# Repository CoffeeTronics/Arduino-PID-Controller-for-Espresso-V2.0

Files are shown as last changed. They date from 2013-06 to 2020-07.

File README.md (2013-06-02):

Arduino-PID-Controller-for-Espresso-V2.0
========================================

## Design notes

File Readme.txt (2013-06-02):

***How to use this software***

Download & install Arduino IDE v1.0 from http://arduino.cc/en/main/software
Copy the CONTENTS of the PID Libraries folder to your Arduino libraries folder.

***To use the Arduino Autotune backend and Processing backend
Download and install the latest version of Processing (I used V1.5.1)
Download and install the ControlP5 library https://code.google.com/p/controlp5/downloads/list
Make sure you get the version of ControlP5 that is compatible with your version of Processing!

Now open Arduino IDE and open the AutotuneMAX31855.ino file
Click on the Verify button (looks like a "tick")
After it compiles, click on the Upload button (looks like a "->"), in the lower left corner when "Compiling" changes to "Uploading", tap the Reset buttin on the controller.
If you get an "avrdude" error, it indicates the Reset button press timing was incorrect. The Reset button press must be done as soon as soon as "Compiling" changes to "Uploading".

Open Processing and open the PID_FrontEnd_v03.pde file
Search (CTRL F) the file for "//EDIT" (without the quotations), these are the parts that the end user can/should change.
Click the Run button (looks like a "Play" button)
This will open a new window displaying the temperature, output and toggle buttons. If the temperature and setpoint traces fail to appear, close the window and click the Runn button again.
The value below or inside the toggle buttons is what the button has been set to, the value to the RHS of the button is what the Arduino backend is set to. 
To change a toggle setting, click on it, enter a value (for P,I,D, etc), click the SEND_TO_ARDUINO button.

To Autotune the controller, put the controller into Manual Mode, then starting from a very low Output value (~50), slowly increase until the system has reached equilibrium with
the Setpoint. Toggle the TOGGLE_TUNING button to ON, check that TUNING_AM is set to MANUAL, then click SEND_TO_ARDUINO.
The Autotune uses the Set Response method to obtain values.
When the TOGGLE_TUNING state to the RHS of the TOGGLE_TUNING button changes from ON to OFF, tuning is complete. The values to the RHS of each P, I and D are the Autotuned
values.

***To use the PID Menu based Controller:
Open the Arduino IDE
Open the Arduino_PID_for_Espresso_V2_0.ino file
Enter the values obtained from the Autotune process into lines 120-122.
Click on the Verify button (looks like a "tick")
After it compiles, click on the Upload button (looks like a "->"), in the lower left corner when "Compiling" changes to "Uploading", tap the Reset buttin on the controller.
If you get an "avrdude" error, it indicates the Reset button press timing was incorrect. The Reset button press must be done as soon as soon as "Compiling" changes to "Uploading".

Once the code has uploaded, the display will read Arduino PID for Espresso, then change to the measured temp and "Menu".

To activate changes, button presses

Press ENTER to enter the Menu. The first item is Brew Espresso, press ENTER to set the Setpoint to the preselected Brew Temperature. The menu will return to root and the controller will move to the Brew Temperature Setpoint.

Press ENTER to enter the Menu. Move right to Steam Milk, press ENTER to set the Setpoint to the preselected Steaming Temperature. The menu will return to root.

Press ENTER to enter the Menu, move right to Brew Temp. the currect setting of Brew Temp will be displayed on the LCD. Press ENTER to enable changing of the Setpoint. The display will read Set Brew Point.
Use the L and R buttons to decrease and increase the Brewing Setpoint. When you have the Brew Setpoint you want, press ENTER to set it. The menu will return to root and the controller will move to the Setpoint. 
Now when you select Brew Espresso, the setpoint will move to the setpoint you have selected.

Press ENTER to enter the Menu, move right to Steam Temp, the currect setting of Steam Temp will be displayed on the LCD. Press ENTER to enable changing of the Steam Temp setting. The display will read Set Steam Point.
Use the L and R buttons to decrease and increase the Steaming Setpoint. When you have the Steaming Setpoint you want, press ENTER to set it. The menu will return to root and the controller will move to the Setpoint.
Now when you select Steam Milk, the setpoint will move to the setpoint you have selected.

Press ENTER to enter the Menu, move right to Offset. The current temp offset between the boiler and the grouphead will be displayed on the LCD. Press ENTER to enable changing of the Offset setting. the display will read Set Offset.
Us the L and R button to decrease and increase the Offset between the boiler and grouphead. When you have the offset you want, press ENTER. The menu will return to root and the controller will move to the Setpoint + Offset.

Currently in the Menu, there is a menu item named Scale, this is for a future update, where the user will be able to select whether to diplay temps in Celcius or Fahrenheit. 

If you are in the Menu and wish to exit without changing any settings, press the ESC button.

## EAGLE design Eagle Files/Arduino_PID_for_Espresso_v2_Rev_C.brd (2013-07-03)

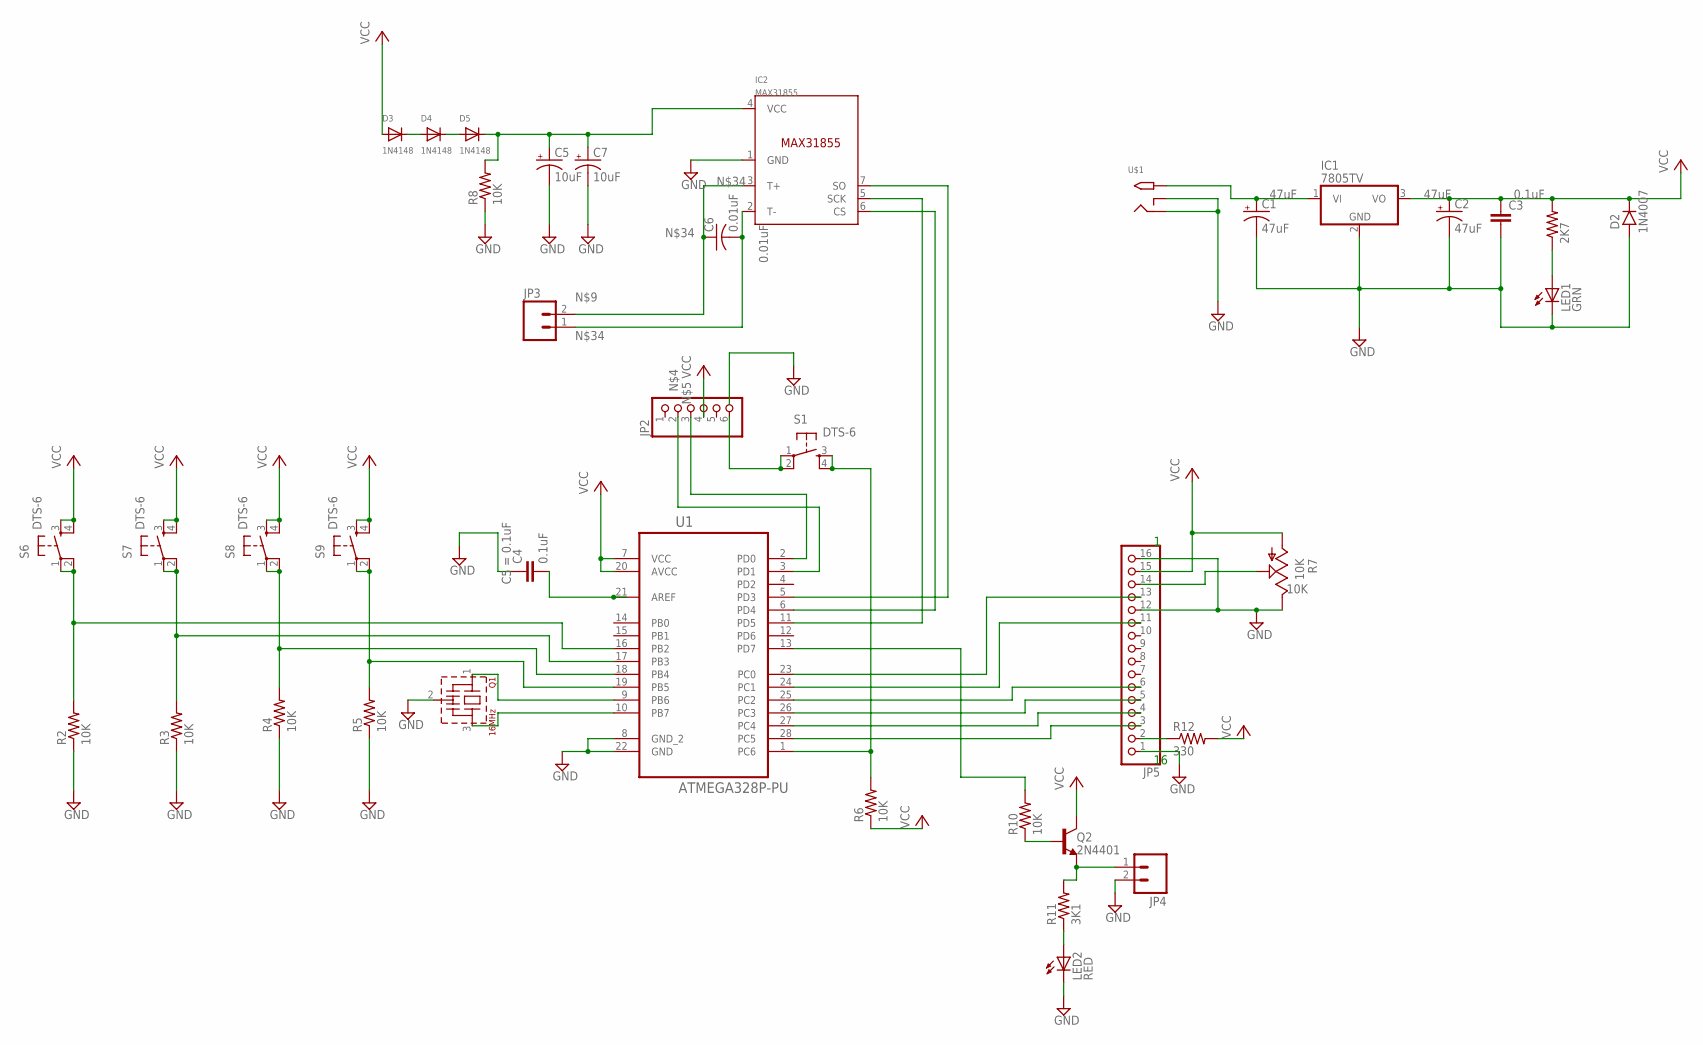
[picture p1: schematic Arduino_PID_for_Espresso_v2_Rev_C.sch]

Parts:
C1, C2: 47uF; TT5D6
C3: C-EU025-024X044; C025-024X044
C4: 0.1uF; C025-024X044
C5, C7: 10uF; CPOL-RADIAL-10UF-25V
C6: 0.01uF; C025-024X044
D2: 1N4007; DO41-3
D3, D4, D5: 1N4148; DO-1N4148
IC1: 7805TV; TO220V
IC2: MAX31855; SOIC8
JP2: PINHD-1X6/90; 1X06/90
JP3, JP4: M023.5MM; SCREWTERMINAL-3.5MM-2
JP5: PINHD-1X16; 1X16
LED1: GRN; LED3MM
LED2: RED; LED3MM
Q1: 16MHz; CSTLA_T
Q2: 2N4401; TO92-
R1: 2K7; AXIAL-0.4
R2, R3, R4, R5, R6, R8, R10: 10K; 1/6W-RES
R7: 10K; B25P
R11: 3K1; AXIAL-0.4
R12: 330; AXIAL-0.4
S1, S6, S7, S8, S9: DTS-6
U1: ATMEGA328P-PU; DIP254P762X457-28
U$1: 2.1MMJACKTHM; PJ-102A

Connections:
GND: C1.-, C2.-, C3.2, C4.1, C5.2 (-), C7.2 (-), D2.A, IC1.2 (GND), IC2.1 (GND), JP2.6, JP4.2, JP5.1, JP5.12, JP5.16, LED1.K (C), LED2.K (C), Q1.2 (VSS), R2.1, R3.1, R4.1, R5.1, R7.E, R8.1, S1.1, S1.2, U1.8 (GND_2), U1.22 (GND), U$1.RING, U$1.RING_SW
unnamed: C1.+, IC1.1 (VI), U$1.TIP
unnamed: C4.2, U1.21 (AREF)
unnamed: LED1.A, R1.P$1 (1)
unnamed: JP2.2, U1.3 (PD1)
unnamed: JP2.3, U1.2 (PD0)
unnamed: R2.2, S6.1, S6.2, U1.16 (PB2)
unnamed: JP5.14, R7.S
unnamed: JP5.2, R12.P$1 (1)
unnamed: C6.2, IC2.2 (T-), JP3.1
unnamed: R4.2, S8.1, S8.2, U1.18 (PB4)
unnamed: Q1.1, U1.9 (PB6)
unnamed: Q1.3, U1.10 (PB7)
unnamed: R6.2, S1.3, S1.4, U1.1 (PC6)
unnamed: R3.2, S7.1, S7.2, U1.17 (PB3)
unnamed: R5.2, S9.1, S9.2, U1.19 (PB5)
unnamed: JP5.3, U1.28 (PC5)
unnamed: JP5.4, U1.27 (PC4)
unnamed: IC2.6 (CS), U1.6 (PD4)
unnamed: JP5.5, U1.26 (PC3)
unnamed: IC2.7 (SO), U1.5 (PD3)
unnamed: IC2.5 (SCK), U1.11 (PD5)
unnamed: D3.C, D4.A
unnamed: D4.C, D5.A
unnamed: C5.1 (+), C7.1 (+), D5.C, IC2.4 (VCC), R8.2
unnamed: JP5.6, U1.25 (PC2)
unnamed: JP5.11, U1.24 (PC1)
unnamed: JP5.13, U1.23 (PC0)
unnamed: Q2.2 (B), R10.1
unnamed: JP4.1, Q2.3 (E), R11.P$2 (2)
unnamed: R10.2, U1.13 (PD7)
unnamed: LED2.A, R11.P$1 (1)
unnamed: C6.1, IC2.3 (T+), JP3.2
VCC: C2.+, C3.1, D2.C, D3.A, IC1.3 (VO), JP2.4, JP5.15, Q2.1 (C), R1.P$2 (2), R6.1, R7.A, R12.P$2 (2), S6.3, S6.4, S7.3, S7.4, S8.3, S8.4, S9.3, S9.4, U1.7 (VCC), U1.20 (AVCC)

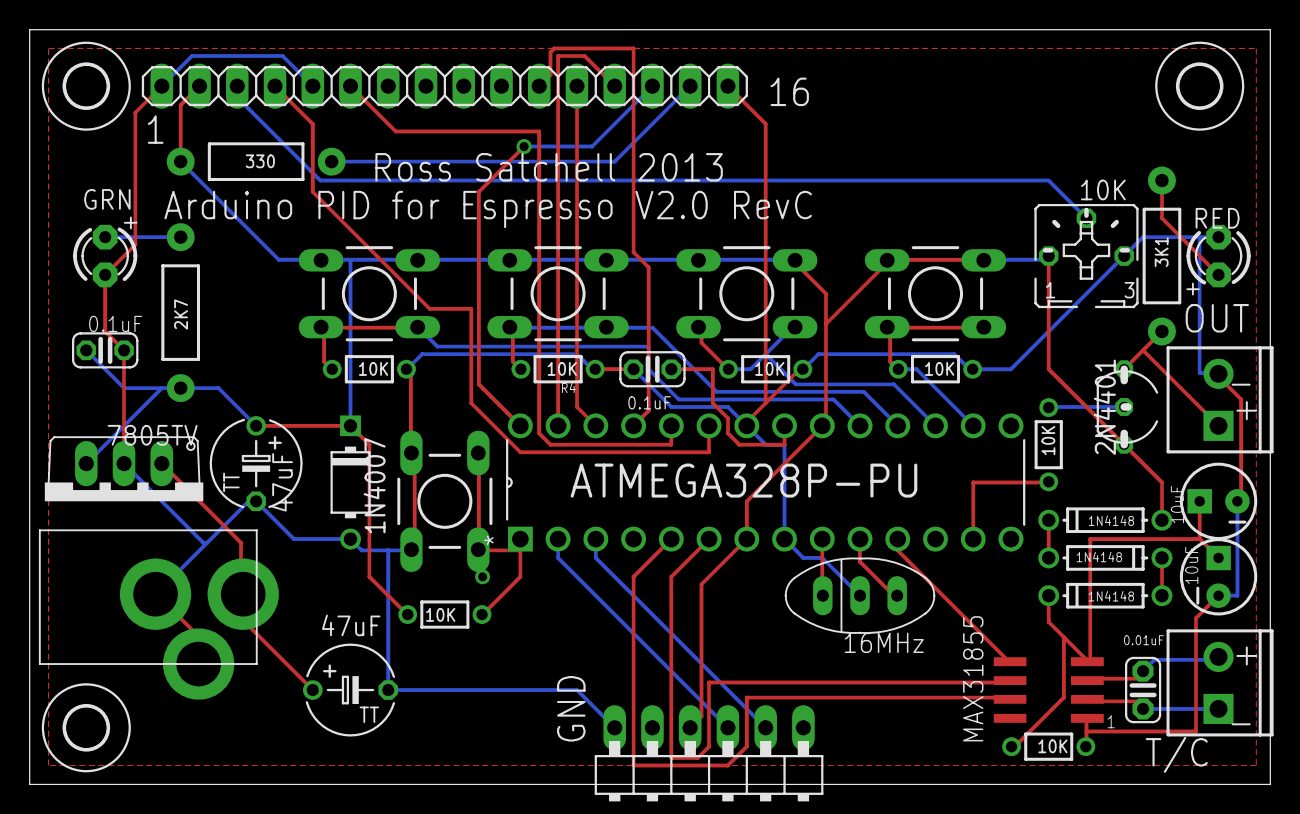
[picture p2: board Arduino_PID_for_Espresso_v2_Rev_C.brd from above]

Board: 2 copper layers, 83.5 x 50.8 mm, 42 parts (0 on the bottom side), 34 nets.

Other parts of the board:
U$2, U$3, U$4: 2,8

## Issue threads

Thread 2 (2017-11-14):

Error on compiling.  2 variables not declared.  Arduino 1.8.3

ML-Weiss, 2017-11-14:
Arduino_PID_for_Espresso_v2_0:87: error: 'menuUsed' was not declared in this scope

 MenuBackend menu = MenuBackend(menuUsed,menuChanged);

                                ^

Arduino_PID_for_Espresso_v2_0:87: error: 'menuChanged' was not declared in this scope

 MenuBackend menu = MenuBackend(menuUsed,menuChanged);

ML-Weiss, 2017-11-15:
Figured out the problem:

Add the following before MenuBackend(menuUseEvent,menuChangeEvent);

static void menuChangeEvent(MenuChangeEvent changed);
static void menuUseEvent(MenuUseEvent used);

Norrox, 2017-11-23:
@ML-Weiss
I changed what you said above but now we are getting these errors :S

C:\Users\UK\AppData\Local\Temp\cc1UkDbY.ltrans2.ltrans.o: In function `__base_ctor ':

C:\Program Files (x86)\Arduino\libraries\MenuBackend/MenuBackend.h:151: undefined reference to `menuChangeEvent(MenuChangeEvent)'

C:\Program Files (x86)\Arduino\libraries\MenuBackend/MenuBackend.h:151: undefined reference to `menuChangeEvent(MenuChangeEvent)'

C:\Program Files (x86)\Arduino\libraries\MenuBackend/MenuBackend.h:152: undefined reference to `menuUseEvent(MenuUseEvent)'

C:\Program Files (x86)\Arduino\libraries\MenuBackend/MenuBackend.h:152: undefined reference to `menuUseEvent(MenuUseEvent)'

collect2.exe: error: ld returned 1 exit status

exit status 1
Error compiling for board Arduino/Genuino Uno.

CoffeeTronics, 2017-11-24:
I found that using function prototypes fixed that problem.

On Nov 23, 2017 2:51 PM, "Christoffer Karlsson" <notifications@github.com>
wrote:

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

Arduino-n00b, 2019-08-06:
Hello folks.

I ran into this project and I think it is great.

I am having one issue after looking over the code and made the following corrections.

Add the following before MenuBackend(menuUseEvent,menuChangeEvent);

static void menuChangeEvent(MenuChangeEvent changed);
static void menuUseEvent(MenuUseEvent used);

After that it seemed to work aside from this error code:

Error compiling for board Arduino/Genuino Uno.

What am I doing wrong?

P.S. I want to use an SPI interface for the LCD but only after I can get it to compile with my IDE for my Uno.

I will share my alterations to this project and thank you in advance.

hikerlt1951, 2020-07-10:
Trying to compile this version V2.0, and get errors ( attached below). I am using the Jameco PID Temperature Controller kit part # 2190178, running arduino IDE 1.8.13 on windows 10 PC.

QUESTION - does anyone have a newer version that works, from the "Arduino PID for Espresso V2.0 by Ross Satchell 2013" ??

**Errors found when compiling V2.0:**

Arduino: 1.8.13 (Windows 10), Board: "Arduino Uno"

sketch_jul10b:87:32: error: 'menuUsed' was not declared in this scope

 MenuBackend menu = MenuBackend(menuUsed,menuChanged);

                                ^~~~~~~~

C:\Users\LT\AppData\Local\Temp\arduino_modified_sketch_182912\sketch_jul10b.ino:87:32: note: suggested alternative: 'menu'

 MenuBackend menu = MenuBackend(menuUsed,menuChanged);

                                ^~~~~~~~

                                menu

sketch_jul10b:87:41: error: 'menuChanged' was not declared in this scope

 MenuBackend menu = MenuBackend(menuUsed,menuChanged);

                                         ^~~~~~~~~~~

C:\Users\LT\AppData\Local\Temp\arduino_modified_sketch_182912\sketch_jul10b.ino: In function 'void setup()':

sketch_jul10b:679:6: error: redefinition of 'void setup()'

 void setup() {

      ^~~~~

C:\Users\LT\AppData\Local\Temp\arduino_modified_sketch_182912\sketch_jul10b.ino:132:6: note: 'void setup()' previously defined here

 void setup() {

      ^~~~~

C:\Users\LT\AppData\Local\Temp\arduino_modified_sketch_182912\sketch_jul10b.ino: In function 'void loop()':

sketch_jul10b:684:6: error: redefinition of 'void loop()'

 void loop() {

      ^~~~

C:\Users\LT\AppData\Local\Temp\arduino_modified_sketch_182912\sketch_jul10b.ino:171:6: note: 'void loop()' previously defined here

 void loop() {

      ^~~~

Multiple libraries were found for "Wire.h"

 Used: C:\Program Files (x86)\Arduino\hardware\arduino\avr\libraries\Wire

 Not used: C:\Program Files (x86)\Arduino\libraries\Wire

exit status 1

'menuUsed' was not declared in this scope

This report would have more information with
"Show verbose output during compilation"
option enabled in File -> Preferences.

hikerlt1951, 2020-07-11:
Thank You !

The fix in the program that you did works great !

Closed 2020-07-19.

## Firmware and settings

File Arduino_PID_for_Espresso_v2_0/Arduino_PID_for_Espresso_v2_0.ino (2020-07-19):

/*
********************************************************
  Arduino PID for Espresso V2.0 by Ross Satchell 2013  *
********************************************************
  This code is intended for single boiler espresso machines such as the Rancilio Silvia (I have been using one as a test machine)
  However it can be easily adapted for double boiler machines by setting up separate PID calls for each boiler. Of course seperate thermocouples and MAX31855's would be required
  It can be adapted for pretty much any application where a PID controller and a menu system is needed
  
 The code for this has been borrowed from several sources and modified to suit this purpose.
 It is a work in progress and will continue to be updated as time permits around my studies.
 
 I would like to thank Brett Beauregard http://brettbeauregard.com/blog for writing the PID library and answering my questions, 
 Konstantine Polanski for combining Brett's Autotune front end and backend for easy acquisition of initial tuning parameters   https://groups.google.com/forum/?fromgroups#!topic/diy-pid-control/4bm_SQrPe8c
 Adafruit for writing the MAX31855 library https://github.com/adafruit/Adafruit-MAX31855-library
 Alexander Brevig http://alexanderbrevig.github.io/ for writing the original menubackend library, 
 Giuseppe Di Cillo http://www.coagula.org/ for modifying the menubackend library to return to root,
 the Arduino community for providing the LCD library http://arduino.cc/en/Reference/LiquidCrystal?from=Tutorial.LCDLibrary  and for helping me solve problems,
 and my friend Daniel Croft for lending me his Rancilio Silvia, helping me along the way and committing code to Github for me!
 
 For those not very familiar with PID, I highly recommend Brett's Beginners posts http://brettbeauregard.com/blog/2011/04/improving-the-beginners-pid-introduction/
  
 This code has been tested in Arduino IDE V1.0 
 For modification and debugging, uncomment the Serial.print lines to print to the Serial Window to make changes easier to detect
 
 The LCD (HD44780 compatible) is connected in 4-bit mode with connections as follows:-
 * LCD Enable pin to digital pin 11
 * LCD D4 pin to digital pin 5
 * LCD D5 pin to digital pin 4
 * LCD D6 pin to digital pin 3
 * LCD D7 pin to digital pin 2
 * LCD R/W pin to ground
 * 10K resistor:
 * ends to +5V and ground
 * wiper to LCD VO pin (pin 3)
 
 To get initial tuning parameter via the Autotune function, join the diy-pid-control google group and see Konstantine's post (linked above, dated Feb 28 2013) for instructions on how to use the Autotune
 frontend and backend.  I plan to integrate my code into the Autotune backend as time allows to simplify things. Currently, I use the autotune to get my parameters, then load them into this code at Lines 118-120.
 */


#include <LiquidCrystal.h>
#include <Adafruit_MAX31855.h>
#include <MenuBackend.h>
#include <Wire.h>
#include <PID_v1.h>
#define RelayPin 7    // SSR connected to Arduino digital 7

int thermoDO = 3;    // MAX31855 Data to Arduino digital 3
int thermoCS = 4;    // MAX31855 Chip Select to Arduino digital 4
int thermoCLK = 5;    // MAX31855 Clock to Arduino digital 5

int right;    // boolean for right button
int left;      // boolean for left button
int enter;    // boolean for enter button
int escape;    // boolean for esc button
int setBrewTemp; //boolean variabke for storing whether user is in Brew Set Point part of menu 
int setSteamTemp;  //boolean variabke for storing whether user is in Steam Set Point part of menu 
int setOffsetBool; // boolean for storing whether user is in Set Offset part of menu
int setTempScale; // boolean for storing whether user is in Set TempScale part of menu
int setBrewing;  // boolean for storing whether user is in Brew Espresso part of menu
int setSteaming;  // boolena for storing whewther user is in Steam Milk part of menu

double brewTempSetting = 200.00; //variable for allowing setting of brew setpoint when in Set Brew Temp part of menu
double steamTempSetting = 250.00; //variable for allowing setting of steam setpoint when in Set Brew Temp part of menu
int intBrewTempSetting;  // int for displaying brewTempSetting in integer for to save lcd space (MAY NOT BE USED)
int intSteamTempSetting;  // int for displaying steamTempSetting in integer for to save lcd space (MAY NOT BE USED)
double offsetSetting;  // value for changing/displaying temp offset from boiler to grouphead 

const int buttonPinLeft = 13; // pin for the Up button
const int buttonPinRight = 10; // pin for the Down button
const int buttonPinEsc = 12; // pin for the Esc button
const int buttonPinEnter = 11; // pin for the Enter button

int lastButtonPushed = 0;    // initialise 
int lastButtonEnterState = LOW; // the previous reading from the Enter input pin
int lastButtonEscState = LOW; // the previous reading from the Esc input pin
int lastButtonLeftState = LOW; // the previous reading from the Left input pin
int lastButtonRightState = LOW; // the previous reading from the Right input pin

long lastEnterDebounceTime = 0; // the last time the output pin was toggled
long lastEscDebounceTime = 0; // the last time the output pin was toggled
long lastLeftDebounceTime = 0; // the last time the output pin was toggled
long lastRightDebounceTime = 0; // the last time the output pin was toggled
long debounceDelay = 300; // the debounce time

//it's necessary to manually add the prototypes for the menuUsed and menuChanged functions here because the Arduino IDE's
//automated function prototype generation system inserts them after they are referenced in the MenuBackend instantiation
void menuUsed(MenuUseEvent used);
void menuChanged(MenuChangeEvent changed);

//Menu variables
MenuBackend menu = MenuBackend(menuUsed,menuChanged);
//initialize menu items
MenuItem menu1Item1 = MenuItem("Brew Espresso");  // select this to load preset brewing setpoint
MenuItem menu1Item2 = MenuItem("Steam Milk");    // select this to load preset steam stepoint
MenuItem menu1Item3 = MenuItem("Brew Temp");    // select this and move to child to change brew setpoint
MenuItem menuItem3SubItem1 = MenuItem("Set Brew Point");  // select this to change brew setpoint
MenuItem menu1Item4 = MenuItem("Steam Temp");            // select this and move to child to change steam setpoint
MenuItem menuItem4SubItem1 = MenuItem("Set Steam Point");  // select this to change steam setpoint
MenuItem menu1Item5 = MenuItem("Offset");                  // select this & move to child to change boiler to group temp offset
MenuItem menuItem5SubItem1 = MenuItem("Set Offset");        // select this to change boiler to group temp offset
MenuItem menu1Item6 = MenuItem("Scale");                    // select this & move to child to change temp scale
MenuItem menuItem6SubItem1 = MenuItem("Set Scale");         // select this to change temp scale

long unsigned lastMillis;
unsigned long nowMillis;
double minutes;

Adafruit_MAX31855 thermocouple(thermoCLK, thermoCS, thermoDO);    // initialise MAX31855 chip

const int numReadings = 10;      // number of readings in array. Increase if slower more stable readings are reqd, reduce if faster readings are reqd

double readings[numReadings];      // the readings from thermocouple
int index = 0;                  // the index of the current reading
double total = 0.0;                  // the running total
double averageF = 0.0;                // the average      
double tempReadF = 0.0;              // temp read in F
double tempReadC = 0.0;              // temp read in C

LiquidCrystal lcd(14, 15, 16, 17, 18, 19);  // initialize the library with the numbers of the interface pins


double Setpoint, Input, Output;    //Define PID variables we'll be connecting to

float Kp = 16.16;    //User inserts PID values obtaines from Autotune here
float Ki = 0.14;    //
float Kd = 480.10;  //

PID myPID(&Input, &Output, &Setpoint,Kp, Ki, Kd, DIRECT);  //Specify the links and initial tuning parameters


int WindowSize = 1000;    // I have found for espresso machines that a 1000ms window does well
unsigned long windowStartTime;  // used in calculating PID output pulse length
double timeNowMins;                // used for logging time in Serial Window


void setup() {
   
  Serial.begin(9600);
  pinMode(buttonPinLeft, INPUT);    //setup input buttons
  pinMode(buttonPinRight, INPUT);
  pinMode(buttonPinEnter, INPUT);
  pinMode(buttonPinEsc, INPUT);
  
  for (int thisReading = 0; thisReading < numReadings; thisReading++)      // initialize all the readings to 0: 
    readings[thisReading] = 0;    


  lcd.begin(16, 2);        // set up the LCD's number of rows and columns: 
  lcd.clear();              // clear LCD
  lcd.setCursor(0,0);        // set cursor to column 1, row 1
  lcd.print("Arduino PID");    //SPLASH
  lcd.setCursor(4,1);          //SCREEN
  lcd.print("for Espresso");
  delay(3000);          // delay for dramatic effect!
  lcd.clear();          // clear lcd
  
  windowStartTime = millis();    // set window to current millis value
  Setpoint = 200;  //Default Setpoint for Rancilio Silvia for approx 200F at the group head
  offsetSetting = 12.00;
  myPID.SetOutputLimits(0, WindowSize);   //tell the PID to range between 0 and the full window size
  myPID.SetMode(AUTOMATIC);    //turn the PID on
  
  //configure menu structure
menu.getRoot().add(menu1Item1);
menu1Item1.addRight(menu1Item2).addRight(menu1Item3).addRight(menu1Item4).addRight(menu1Item5).addRight(menu1Item6);
menu1Item3.add(menuItem3SubItem1);
menu1Item4.add(menuItem4SubItem1);
menu1Item5.add(menuItem5SubItem1); 
menu1Item6.add(menuItem6SubItem1);

menu.toRoot();    // go to root of menu
  
}

void loop() {
  tempRead();    // call temp reading method
  
  if ((millis() - lastMillis) >= 125)  {    //perform calcPID 8 times per second
  calcPID();    // call PID calculation
  readButtons(); //  button reading and navigation split in two procedures because 
  navigateMenus(); //in some situations, the buttons are used for other purpose (eg. to change some settings)
  changeValues(); // scans buttons and menu states
  }
 
}  // end loop

void tempRead()  {
   double c = thermocouple.readCelsius();
   if (isnan(c)) {    //  if c is not a number
     //Serial.println("Something wrong with thermocouple!"); // uncomment if using serial window
     lcd.setCursor(0,0);
     lcd.print("Thermocouple Err");
   } else {
    // Serial.print("C = "); 
    // Serial.println(c);
   }

   tempReadF = thermocouple.readFarenheit();  // read temp in degrees F
   tempReadC = c;                            // temp in degrees C
    
   total= total - readings[index];         
   readings[index] = tempReadF;         // read from the sensor: 
   total= total + readings[index];     // add the reading to the total:    
   index = index + 1;                 // advance to the next position in the array:         
   if (index >= numReadings)          // if we're at the end of the array...
   index = 0;                         // ...wrap around to the beginning:                          
   averageF = total / numReadings;    // calculate the average:
    
   //Serial.print("Internal Temp = ");        // uncomment these lines if checking MAX31855 
   //Serial.println(thermocouple.readInternal());     // internal chip temp via Serial Window
   //Serial.print("Temp ");                    // uncomment these lines if checking MAX31855
   Serial.print(averageF);                  // hot junction temp via Serial Window
   Serial.print("\t");
   lcd.setCursor(9,0);
   lcd.print(averageF);      // print temp to upper RHS of LCD
   lcd.print((char)223);          // print degree symbol
   
   
}
   
void calcPID()  {
  Input = averageF; // PID input is measured averaged temp
  myPID.Compute(); //PID calculation
  
  /************************************************
  * turn the output pin on/off based on pid output
  ************************************************/
  unsigned long now = millis();
  if(now - windowStartTime>WindowSize)    //time to shift the Relay Window
    { 
    windowStartTime += WindowSize;
    }
  if(Output > now - windowStartTime) digitalWrite(RelayPin,HIGH);
  else digitalWrite(RelayPin,LOW);
  
  Serial.print(Output);    // uncomment these lines if
  Serial.print("\t");      // logging data to  
  timeNowMins = millis() / 60000.0;    //Serial 
  Serial.println(timeNowMins);        // Window
}

void menuChanged(MenuChangeEvent changed){

MenuItem newMenuItem=changed.to; //get the destination menu

lcd.setCursor(0,1); //set the start position for lcd printing to the second row, first column

if(newMenuItem.getName()==menu.getRoot()){
  lcd.setCursor(0,0);
  lcd.print("       ");
  lcd.setCursor(0,1);
  lcd.print("Menu            ");
  setBrewTemp = false; 
  setSteamTemp = false;
  setOffsetBool = false;
  setTempScale = false;

}else if(newMenuItem.getName()=="Brew Espresso"){
    lcd.setCursor(0,0);
    lcd.print("       ");
    lcd.setCursor(0,1);
    lcd.print("Brew Espresso   ");
    setBrewTemp = false;
    setSteamTemp = false;
    setBrewing = true;
    setSteaming = false;
    setOffsetBool = false;
    setTempScale = false;

}else if(newMenuItem.getName()=="Steam Milk")  {
    lcd.setCursor(0,0);
    lcd.print("       ");
    lcd.setCursor(0,1);
    lcd.print("Steam Milk      ");
    setBrewTemp = false;
    setSteamTemp = false;
    setOffsetBool = false;
    setTempScale = false;
    setSteaming = true;
    setBrewing = false;

}else if(newMenuItem.getName()=="Brew Temp"){
    lcd.setCursor(0,0);
    lcd.print("       ");
    lcd.setCursor(0,0);
    lcd.print(brewTempSetting);
    lcd.setCursor(0,1);
    lcd.print("Brew Temp       "); 
    setBrewTemp = false;
    setSteamTemp = false;
    setOffsetBool = false;
     setTempScale = false;


}else if (newMenuItem.getName()=="Set Brew Point"){
    lcd.setCursor(0,0);
    lcd.print("       ");
    lcd.setCursor(0,1);  
    lcd.print("Set Brew Point  ");
    lcd.setCursor(0,0);
    lcd.print(brewTempSetting);
    setBrewTemp = true;
    setSteamTemp = false;
    setOffsetBool = false;
    setTempScale = false;
    
}else if (newMenuItem.getName()=="Steam Temp")  {
    lcd.setCursor(0,0);
    lcd.print("       ");
    lcd.setCursor(0,1);
    lcd.print("Steam Temp      ");
    lcd.setCursor(0,0);
    lcd.print(steamTempSetting);
    setBrewTemp = false;
    setSteamTemp = false;
    setOffsetBool = false;
    setTempScale = false;
  
}else if (newMenuItem.getName()=="Set Steam Point")  {
    lcd.setCursor(0,0);
    lcd.print("       ");
    lcd.setCursor(0,0);
    lcd.print(steamTempSetting);
    lcd.setCursor(0,1);
    lcd.print("Set Steam Point ");
    setBrewTemp = false;
    setSteamTemp = true;
    setOffsetBool = false;
    setTempScale = false;


}else if(newMenuItem.getName()=="Offset")  {
    lcd.setCursor(0,0);
    lcd.print("       ");
    lcd.setCursor(0,0);
    lcd.print(offsetSetting);
    lcd.setCursor(0,1);
    lcd.print("Offset          ");
    setBrewTemp =false;
    setSteamTemp = false;
    setOffsetBool = false;
    setTempScale = false;
  
}else if(newMenuItem.getName()=="Set Offset")  {
    lcd.setCursor(0,0);
    lcd.print("       ");
    lcd.setCursor(0,1);
    lcd.print("Set Offset");
    lcd.setCursor(0,0);
    lcd.print(offsetSetting);
    setBrewTemp =false;
    setSteamTemp = false;
    setOffsetBool = true;
    setTempScale = false;
    
}else if(newMenuItem.getName()=="Scale")  {   
    lcd.setCursor(0,0);
    lcd.print("       ");
    lcd.setCursor(0,1);
    lcd.print("Scale  "); 
    setBrewTemp =false;
    setSteamTemp = false;
    setOffsetBool = false;
    setTempScale = false;
    
}else if(newMenuItem.getName()=="Set Scale")  {   
    lcd.setCursor(0,0);
    lcd.print("       ");
    lcd.setCursor(0,1);
    lcd.print("Set Scale");
    setBrewTemp =false;
    setSteamTemp = false;
    setOffsetBool = false;
    setTempScale = true;
    
}else  {
    setBrewTemp =false;
    setSteamTemp = false;
    setTempScale = false;
    }
  }
  
void menuUsed(MenuUseEvent used) {
  
  if ((setBrewTemp == true) && (enter == true))  {
     //Serial.print("brew temp selected = ");  // uncomment for Serial 
     //Serial.println(brewTempSetting);        // Window debugging
     Setpoint = brewTempSetting + offsetSetting;
     menu.toRoot();
     
  }else if ((setSteamTemp == true) && (enter == true))  {
     //Serial.print("Steam temp Selected = ");
     //Serial.println(steamTempSetting);
     Setpoint = steamTempSetting;
     menu.toRoot();
     
    
  }else if ((setOffsetBool == true) && (enter == true))  {
    //Serial.print("Offset now set to ");
    //Serial.println(offsetSetting);
    Setpoint = brewTempSetting + offsetSetting;
    menu.toRoot();
    
  
  }else if ((setBrewing == true) && (enter == true))  {
    Setpoint = brewTempSetting + offsetSetting;
    lcd.setCursor(0,0);
    lcd.print("       ");
    lcd.setCursor(0,0);
    lcd.print(Setpoint);
    //Serial.print("ESPRESSO ");
    //Serial.println(Setpoint);
    menu.toRoot();
    
  }else if ((setSteaming == true) && (enter == true))  {
    Setpoint = steamTempSetting;
    lcd.setCursor(0,0);
    lcd.print("       ");
    lcd.setCursor(0,0);
    lcd.print(Setpoint);
    //Serial.print("STEAMING ");
    //Serial.println(Setpoint);
    menu.toRoot();
    
  
  
  }else{
    
     menu.toRoot();
     Setpoint = brewTempSetting + offsetSetting;
  }
}

void readButtons(){ //read buttons status
int reading;
int buttonEnterState=LOW; // the current reading from the Enter input pin
int buttonEscState=LOW; // the current reading from the input pin
int buttonLeftState=LOW; // the current reading from the input pin
int buttonRightState=LOW; // the current reading from the input pin

//Enter button
// read the state of the switch into a local variable:
reading = digitalRead(buttonPinEnter);

// check to see if you just pressed the enter button 
// (i.e. the input went from LOW to HIGH), and you've waited 
// long enough since the last press to ignore any noise: 

// If the switch changed, due to noise or pressing:
if (reading != lastButtonEnterState) {
// reset the debouncing timer
lastEnterDebounceTime = millis();
} 

if ((millis() - lastEnterDebounceTime) > debounceDelay) {
// whatever the reading is at, it's been there for longer
// than the debounce delay, so take it as the actual current state:
buttonEnterState=reading;
lastEnterDebounceTime=millis();
}

// save the reading. Next time through the loop,
// it'll be the lastButtonState:
lastButtonEnterState = reading;


//Esc button 
// read the state of the switch into a local variable:
reading = digitalRead(buttonPinEsc);

// check to see if you just pressed the Down button 
// (i.e. the input went from LOW to HIGH), and you've waited 
// long enough since the last press to ignore any noise: 

// If the switch changed, due to noise or pressing:
if (reading != lastButtonEscState) {
// reset the debouncing timer
lastEscDebounceTime = millis();
} 

if ((millis() - lastEscDebounceTime) > debounceDelay) {
// whatever the reading is at, it's been there for longer
// than the debounce delay, so take it as the actual current state:
buttonEscState = reading;
lastEscDebounceTime=millis();
}

// save the reading. Next time through the loop,
// it'll be the lastButtonState:
lastButtonEscState = reading; 


//Down button 
// read the state of the switch into a local variable:
reading = digitalRead(buttonPinRight);

// check to see if you just pressed the Down button 
// (i.e. the input went from LOW to HIGH), and you've waited 
// long enough since the last press to ignore any noise: 

// If the switch changed, due to noise or pressing:
if (reading != lastButtonRightState) {
// reset the debouncing timer
lastRightDebounceTime = millis();
} 

if ((millis() - lastRightDebounceTime) > debounceDelay) {
// whatever the reading is at, it's been there for longer
// than the debounce delay, so take it as the actual current state:
buttonRightState = reading;
lastRightDebounceTime =millis();
}

// save the reading. Next time through the loop,
// it'll be the lastButtonState:
lastButtonRightState = reading; 


//Up button 
// read the state of the switch into a local variable:
reading = digitalRead(buttonPinLeft);

// check to see if you just pressed the Down button 
// (i.e. the input went from LOW to HIGH), and you've waited 
// long enough since the last press to ignore any noise: 

// If the switch changed, due to noise or pressing:
if (reading != lastButtonLeftState) {
// reset the debouncing timer
lastLeftDebounceTime = millis();
} 

if ((millis() - lastLeftDebounceTime) > debounceDelay) {
// whatever the reading is at, it's been there for longer
// than the debounce delay, so take it as the actual current state:
buttonLeftState = reading;
lastLeftDebounceTime=millis();;
}

// save the reading. Next time through the loop,
// it'll be the lastButtonState:
lastButtonLeftState = reading; 

//records which button has been pressed
if (buttonEnterState==HIGH){
lastButtonPushed=buttonPinEnter;
enter = true;
right = false;
left = false;

}else if(buttonEscState==HIGH){
lastButtonPushed=buttonPinEsc;
//escape = true;
enter = false;
right = false;
left = false;

}else if(buttonRightState==HIGH){
lastButtonPushed=buttonPinRight;
right = true;
left = false;
enter = false;

}else if(buttonLeftState==HIGH){
lastButtonPushed=buttonPinLeft;
left = true;
right = false;
enter = false;

}else{
lastButtonPushed=0;
enter = false;
right = false;
left = false;
} 
}

void navigateMenus() {
MenuItem currentMenu=menu.getCurrent();

switch (lastButtonPushed){
case buttonPinEnter:
if(!(currentMenu.moveDown())){ //if the current menu has a child and has been pressed enter then menu navigate to item below
menu.use();
}else{ //otherwise, if menu has no child and has been pressed enter the current menu is used
menu.moveDown();
}
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

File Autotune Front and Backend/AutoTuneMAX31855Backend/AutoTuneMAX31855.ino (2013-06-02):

/* 
 * Arduino PID AutoTune Code
 * by Brett Beauregard
 * April 2011
 
 
 * February 2013
 * Edited by Konstantine @Palanski to incorporate Autotune and PID Front End
 * Edits and additions marked with //KP
 
 *HOW TO USE:
 * Upload this code to Arduino with the appropriate pin settings and sensor settings.
 * Download Processing with the ControlP5 library and run the PID_FrontEnd_v03 (set appropriate COM)
 * myPort = new Serial(this, Serial.list()[0], 9600);  //Edit the [0] value to select appropriate COM
 * Allow the system to come to equilibrium after setting an initial setpoint
 * When system is at equilibrium, toggle Tuning to 'On'.
 * When the tuning is finished, the Tuning toggle will go to 'Off', and the new PID values will be on the screen.
 * SEARCH ALL CODE FOR //KP to see where edits MUST be made by YOU for this to be effective in the tuning
*/


//DS18B20 OneWire and DallasTemperature Library Initialization
//#include <OneWire.h>
//#include <DallasTemperature.h>
//#define oneWireBus 9
//OneWire oneWire(oneWireBus);
//DallasTemperature sensors(&oneWire);

//PID and PID Autotune Library Initialization

#include <PID_v1.h>
#include <PID_AutoTune_v0.h>
#include <LiquidCrystal.h>
#include "Adafruit_MAX31855.h"

int thermoDO = 3;
int thermoCS = 4;
int thermoCLK = 5;
Adafruit_MAX31855 thermocouple(thermoCLK, thermoCS, thermoDO);

const int numReadings = 10;

double readings[numReadings];      // the readings from the analog input
int index = 0;                  // the index of the current reading
double total = 0.0;                  // the running total
double average = 0.0;                // the average      
double tempReadF = 0.0;

// initialize the library with the numbers of the interface pins
LiquidCrystal lcd(14, 15, 16, 17, 18, 19);



//
byte ATuneModeRemember=2;
double Input, Output; 
double Setpoint = 212; //EDIT Set initial Setpoint
double kp=16,ki=0.5,kd=4; //KP Set intial PID parameters, if you have any.

double kpmodel=1.5, taup=100, theta[50];
double OutputStart=5;

double aTuneStep=750, aTuneNoise=1, aTuneStartValue=750; //KP Set aTuneStep to ensure noticeable heating and cooling from aTuneStartValue
unsigned int aTuneLookBack=60000; //KP How far back to look back to find maxima and minima. 
// For Slow processes this will be large, for fast processes, this will be smaller.

unsigned long  modelTime, serialTime;

PID myPID(&Input, &Output, &Setpoint,kp,ki,kd, DIRECT);
PID_ATune aTune(&Input, &Output);

//set to false to connect to the real world
boolean useSimulation = false; //EDIT Keep false unless simulating

//Tuning?
boolean tuning = false; //EDIT Keep False


const int relayPin = 7;    //EDIT Relay settings. (I'm running my code with a relay).
unsigned int WindowSize = 1000;
unsigned long windowStartTime;

void setup()
{ 
  windowStartTime = millis();
  pinMode(relayPin, OUTPUT); // Set relayPin as Output
  
  if(useSimulation)
  {
    for(byte i=0;i<50;i++)
    {
      theta[i]=OutputStart;
    }
    modelTime = 0;
  }
  
  //tell the PID to range between 0 and the full window size
  myPID.SetOutputLimits(0, WindowSize);
  
  //Setup the pid 
  myPID.SetMode(AUTOMATIC);

  if(tuning)
  {
    tuning=false;
    changeAutoTune();
    tuning=true;
  }
  
  aTune.SetControlType(1); //EDIT Set 0 for PI control and 1 for PID control autotuning parameters
  
  serialTime = 0;
  Serial.begin(9600);

}

void loop()
{
 unsigned long now = millis(); 
 if(!useSimulation)
  { //pull the Input in from the thermocouple
   //Pass to Input of PID
   tempRead();

   Input = average;
  }
  
  if(tuning)
  {
    byte val = (aTune.Runtime());
    if (val!=0)
    {
      tuning = false;
    }
    if(!tuning)
    { //we're done, set the tuning parameters
      kp = aTune.GetKp();
      ki = aTune.GetKi();
      kd = aTune.GetKd();
      myPID.SetTunings(kp,ki,kd);
      Serial.print("P="); Serial.print(kp);
      Serial.print("I="); Serial.print(ki);
      Serial.print("D="); Serial.print(kd);
      AutoTuneHelper(false);
    }
  }
  else myPID.Compute();
  
  if(useSimulation)
  {
    theta[30]=Output;
    if(now>=modelTime)
    {
      modelTime +=100; 
      DoModel();
    }
  }
  else // This is optimized for Relay output.
  { 
  if(now - windowStartTime>WindowSize)
  { //time to shift the Relay Window
    windowStartTime += WindowSize;
  }
  if(Output > now - windowStartTime) digitalWrite(relayPin,HIGH);
  else digitalWrite(relayPin,LOW);  
}
  
  //send-receive with processing if it's time
  if(millis()>serialTime)
  {
    SerialReceive();
    SerialSend();
    serialTime+=500;
  }
}


/********************************************
 * Serial Communication functions / helpers
 ********************************************/


union {                // This Data structure lets
  byte asBytes[24];    // us take the byte array
  float asFloat[6];    // sent from processing and
}                      // easily convert it to a
foo;                   // float array


void changeAutoTune()
{
 if(!tuning)
  {
    //Set the Output to the desired starting frequency.
    aTuneStartValue = Output; //KP Initial aTuneStartValue will be = Output at Toggle
    aTune.SetNoiseBand(aTuneNoise);
    aTune.SetOutputStep(aTuneStep);
    aTune.SetLookbackSec((int)aTuneLookBack);
    AutoTuneHelper(true);
    tuning = true;
  }
  else
  { //cancel autotune
    aTune.Cancel();
    tuning = false;
    AutoTuneHelper(false);
  }
}

void AutoTuneHelper(boolean start)
{
  if(start)
    ATuneModeRemember = myPID.GetMode();
  else
    myPID.SetMode(ATuneModeRemember);
}


void SerialSend()
{
Serial.print("PID ");
  Serial.print(Setpoint);   
  Serial.print(" ");
  Serial.print(Input);   
  Serial.print(" ");
  Serial.print(Output);   
  Serial.print(" ");
  Serial.print(myPID.GetKp());   
  Serial.print(" ");
  Serial.print(myPID.GetKi());   
  Serial.print(" ");
  Serial.print(myPID.GetKd());   
  Serial.print(" ");
  if(myPID.GetMode()==AUTOMATIC) Serial.print("Automatic");
  else Serial.print("Manual");  
  Serial.print(" ");
  if(myPID.GetDirection()==DIRECT) Serial.print("Direct");
  else Serial.print("Reverse");
  Serial.print(" ");
  if(tuning==false) Serial.println("Off"); //KP Added the On/Off for Tuning Toggle
  else Serial.println("On");
}
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

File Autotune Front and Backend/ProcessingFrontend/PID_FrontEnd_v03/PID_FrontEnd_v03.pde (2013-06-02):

/********************************************************
 * Arduino PID Tuning Front-End,  Version 0.3
 * by Brett Beauregard
 * License: Creative-Commons Attribution Share-Alike
 * April 2011
 *
 * This application is designed to interface with an
 * arduino running the PID Library.  From this Control
 * Panel you can observe & adjust PID performance in 
 * real time
 *
 * The ControlP5 library is required to run this sketch.
 * files and install instructions can be found at
 * http://www.sojamo.de/libraries/controlP5/
 * 
 
 * February 2013
 * Edited by Konstantine @Palanski and Ross Satchell to incorporate easier tuning for espresso machines.
 * Edits and additions marked with //EDIT
 ********************************************************/

import java.nio.ByteBuffer;
import processing.serial.*;
import controlP5.*;

/***********************************************
 * User spcification section
 **********************************************/
int windowWidth = 900;      // set the size of the 
int windowHeight = 600;     // form

float InScaleMin = 150;    // set the Y-Axis Min  //EDIT Set your window MIN TEMP here
float InScaleMax = 230;    // and Max for both    //EDIT Set your window MAX TEMP here
float OutScaleMin = 0;      // the top and       
float OutScaleMax = 1000;    // bottom trends     //EDIT If you have used a different Window Size in the Arduino_PID code (default is 1000), match it here.


int windowSpan = 3000000;    // number of mS into the past you want to display    //EDIT Set how far you want to look back here in ms
int refreshRate = 100;      // how often you want the graph to be reDrawn;

//float displayFactor = 1; //display Time as Milliseconds    //EDIT If you are controlling an extremely fast process, uncomment this line
//float displayFactor = 1000; //display Time as Seconds      //EDIT If you are controlling an pretty fast process, uncomment this line
float displayFactor = 60000; //display Time as Minutes      //EDIT If you uncomment either of the above 2 lines, comment this line out

String outputFileName = ""; // if you'd like to output data to 
// a file, specify the path here

/***********************************************
 * end user spec
 **********************************************/

int nextRefresh;
int arrayLength = windowSpan / refreshRate+1;
int[] InputData = new int[arrayLength];     //we might not need them this big, but
int[] SetpointData = new int[arrayLength];  // this is worst case
int[] OutputData = new int[arrayLength];


float inputTop = 25;
float inputHeight = (windowHeight-70)*2/3;
float outputTop = inputHeight+50;
float outputHeight = (windowHeight-70)*1/3;

float ioLeft = 150, ioWidth = windowWidth-ioLeft-50;
float ioRight = ioLeft+ioWidth;
float pointWidth= (ioWidth)/float(arrayLength-1);

int vertCount = 10;

int nPoints = 0;

float Input, Setpoint, Output;

boolean madeContact =false;
boolean justSent = true;

Serial myPort;

ControlP5 controlP5;
controlP5.Button AMButton, DRButton, TuningButton;
controlP5.Textlabel AMLabel, AMCurrent, InLabel, TuningLabel, TuningCurrent, 
OutLabel, SPLabel, PLabel, 
ILabel, DLabel,DRLabel, DRCurrent;
controlP5.Textfield SPField, InField, OutField, 
PField, IField, DField;

PrintWriter output;
PFont AxisFont, TitleFont;
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

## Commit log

2013-07-03 Added Eagle Schematic & PCB files
    [Arduino_PID_for_Espresso_v2_Rev_C.brd, Arduino_PID_for_Espresso_v2_Rev_C.sch]
2020-07-11 Force correct placement of function prototypes
    The Arduino sketch preprocessor automatically generates function prototypes for any function in a .ino file that doesn't already have a prototype. This system usually works perfectly, but in some rare cases the prototype is inserted at the wrong place in the code. That issue was ocurring in this sketch when compiled with modern versions of the Arduino development software. The solution is to manually add the problematic function prototypes in the correct place.
    It's likely that the function prototypes happened to be inserted at the correct location at the time this sketch was written. In the seven years since that time, Arduino has done a maj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
    [Arduino_PID_for_Espresso_v2_0.ino]

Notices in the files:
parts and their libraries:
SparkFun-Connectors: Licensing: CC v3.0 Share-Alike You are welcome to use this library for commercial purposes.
